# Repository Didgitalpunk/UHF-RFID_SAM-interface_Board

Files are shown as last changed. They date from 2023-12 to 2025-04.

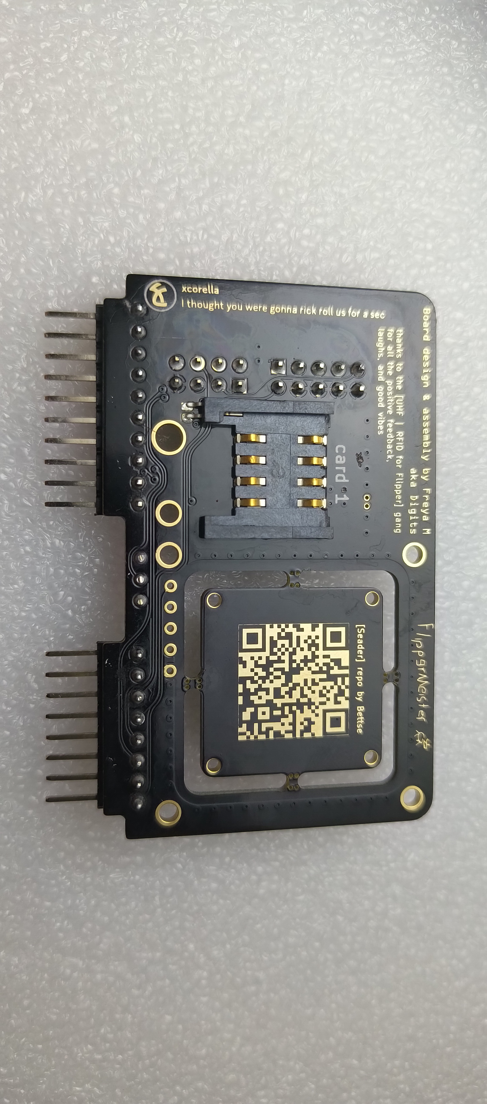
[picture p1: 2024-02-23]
P_20240223_211543.jpg

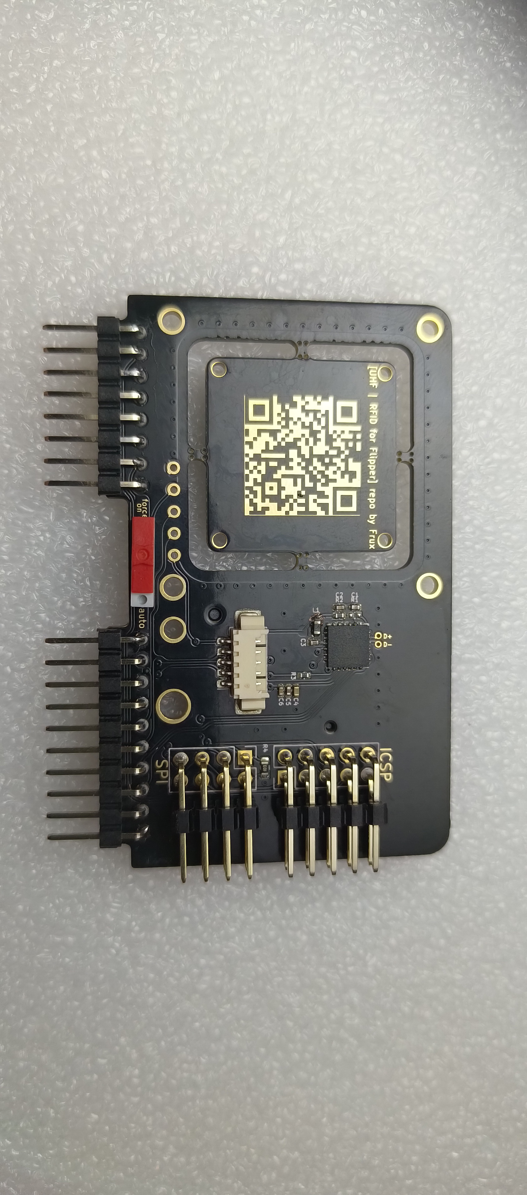
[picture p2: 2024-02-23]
P_20240223_211611.jpg

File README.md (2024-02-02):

# UHF-RFID SAM interface Board
A PCB for connecting UHF-RFID readers to your flipper, and a SEC1210 iC to allow you to interface and use a SAM.
Also has a 6 pin ICSP header and an SPI header to use with various FAPs.

This board is made for the flipper zero and uses https://github.com/frux-c/uhf_rfid for the UHF-RFID part, and https://github.com/bettse/seader for the SAM part.
The SPI and ICSP headers on this board are here for use with the SPI_Mem_Manager fap, and the AVR_Flasher fap respectively, among, I'm sure, others faps.

Thanks to the UHF|RFID gang over on the flipper zero discord for all the nice comments, all the info, and especially, the initial push on the UHF|RFID project!

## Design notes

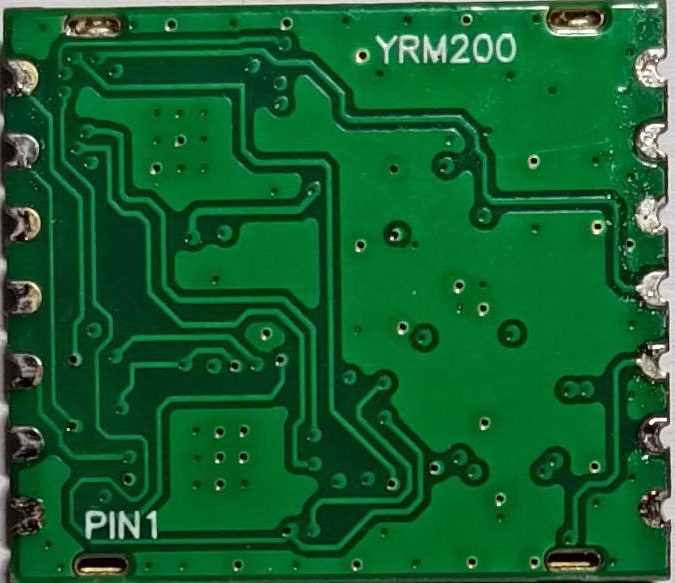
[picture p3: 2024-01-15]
YRM1001/YRM200/back.jpg

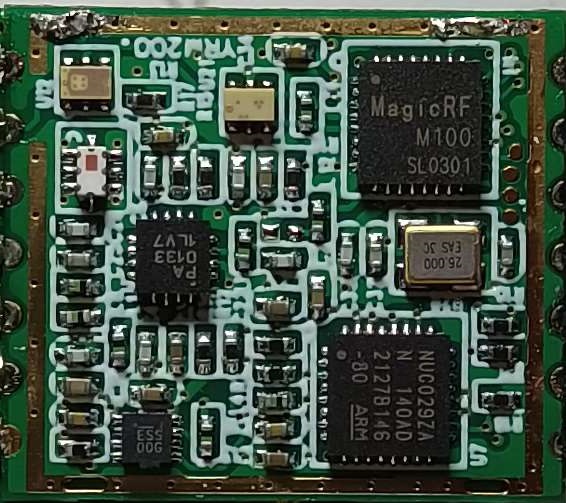
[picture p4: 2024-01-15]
YRM1001/YRM200/front.jpg

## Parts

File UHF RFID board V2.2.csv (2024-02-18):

Reference | Value | Footprint | Source | Qty
C1, C3, C5, C8 | 1uF | Capacitor_SMD:C_0402_1005Metric | https://www.mouser.fr/ProductDetail/Murata-Electronics/GRM155R61C105KA12J?qs=hNud%2FORuBR0BebdCvsO0Bw%3D%3D | 4
C2, C6, C9 | 0.1uF | Capacitor_SMD:C_0402_1005Metric | https://www.mouser.fr/ProductDetail/581-KGM05AR51A104KH | 3
C4, C7 | 10uF | Capacitor_SMD:C_0402_1005Metric | https://www.mouser.fr/ProductDetail/81-GRM155R61A106ME1J | 2
D1 | LED | Custom LEDs:side-edge mount | https://www.mouser.fr/ProductDetail/604-APA1606VRBXF5MAV | 1
eSAM1, eSAM2 | ~ | Custom footprints:DFN-8-splitEP_5x5mm_P1.27mm_EP2.5x4mm |  | 2
J1-1 | FZ_full_module-1 | Flipper modules:FZ full module | https://www.mouser.fr/ProductDetail/855-M20-9961045 | 1
J1-2 | FZ_full_module-2 |  | https://www.mouser.fr/ProductDetail/855-M20-9960845 | 1
J2 | picoblade | Connector_Molex:Molex_PicoBlade_53261-0571_1x05-1MP_P1.25mm_Horizontal | https://www.mouser.fr/ProductDetail/Molex/53261-0571?qs=Z4ettq%2Fvyk9tUNWvtq%2FUoA%3D%3D | 1
J3 | SPI | Connector_PinHeader_2.54mm:PinHeader_2x04_P2.54mm_Vertical | https://www.mouser.fr/ProductDetail/Harwin/M20-9950445?qs=WS5Jv%252B%252Bx1qUpJ0yV%252BQiEtg%3D%3D | 1
J4 | ICSP | Connector_PinHeader_2.54mm:PinHeader_2x03_P2.54mm_Vertical | https://www.mouser.fr/ProductDetail/Harwin/M20-9950345?qs=%252Bk6%2F5FB6qrkhHG1%252BkQ5u%252BQ%3D%3D | 1
L1 | 2A/0.05DCR | Inductor_SMD:L_0603_1608Metric | https://www.mouser.fr/ProductDetail/Murata-Electronics/BLM18EG221SN1D?qs=uSeJpk%2F8In2DDeSj2a4KGA%3D%3D | 1
R1 | 1M | Resistor_SMD:R_0402_1005Metric | DNP | 0
R2 | 100K | Resistor_SMD:R_0402_1005Metric | https://www.mouser.fr/ProductDetail/Bourns/CR0402-FX-1003GLF?qs=URDPQ%2Fj0cz1ZruPSJQ7fsA%3D%3D | 1
R3, R5 | 43R | Resistor_SMD:R_0402_1005Metric | https://www.mouser.fr/ProductDetail/?qs=ePR1ZvdkOKKmGsQnUArpPA%3D%3D | 2
R4 | 10k | Resistor_SMD:R_0603_1608Metric | https://www.mouser.fr/ProductDetail/652-CR0603-JW-103ELF | 1
R6 | 330R | Resistor_SMD:R_0402_1005Metric | https://www.mouser.fr/ProductDetail/Bourns/CR0402-FX-3300GLF?qs=SFHnMgm9IsyaL104gdTOhg%3D%3D | 1
SAM1, SAM2 | SIM_Card | Custom footprints:SIMMP-00801B000-G sim card connector w plated holes | https://fr.farnell.com/multicomp/simmp-00601b000-g/connecteur-mini-sim-6pin/dp/2211802?st=sim | 2
U1 | YRM1001 | RFID_NFC_footprints:UHF_RFID_35x35_YRM1001_module_through-board no_header with mounting holes 35-40 | https://fr.aliexpress.com/item/1005005296512846.html | 1
U2 | SEC1210 | Package_DFN_QFN:QFN-24-1EP_5x5mm_P0.65mm_EP3.2x3.2mm | https://www.mouser.fr/ProductDetail/Microchip-Technology/SEC1210-I-PV-UR2?qs=Gd3Cm49KlLPWS64hHCSBQA%3D%3D | 1

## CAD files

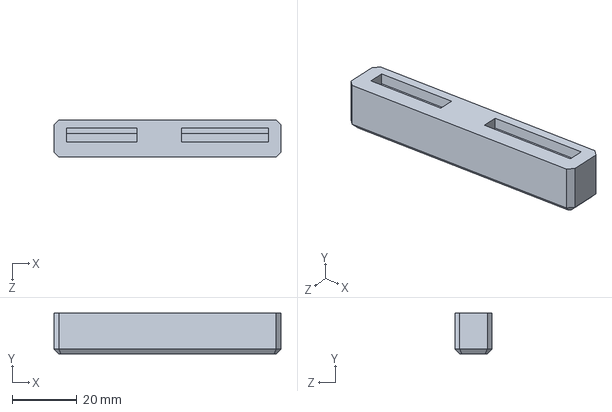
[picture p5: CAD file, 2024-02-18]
Case V2.0/case parts/UHF RFID board V2.0-Pin cover.SLDPRT
70.1 x 12.6 x 11.5 mm

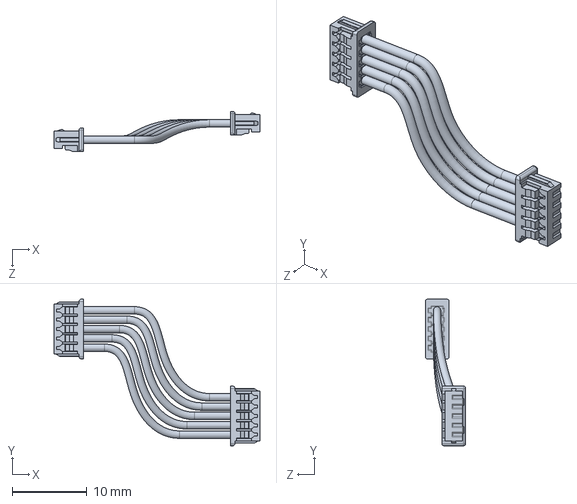
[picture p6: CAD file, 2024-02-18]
Case V2.0/picoblade cable.SLDPRT
27.6 x 19.6 x 5.40 mm

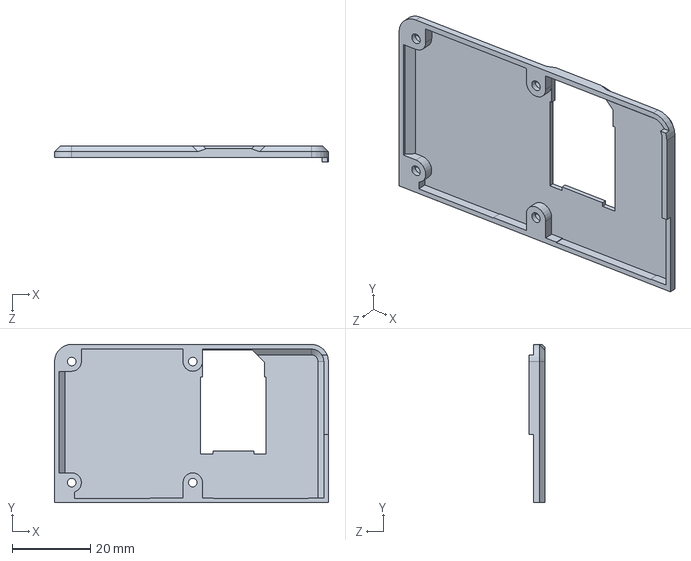
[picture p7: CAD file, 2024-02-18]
Case V2.0/case parts/UHF RFID board V2.0-Bottom case open SAM.SLDPRT
70.1 x 40.5 x 4.20 mm

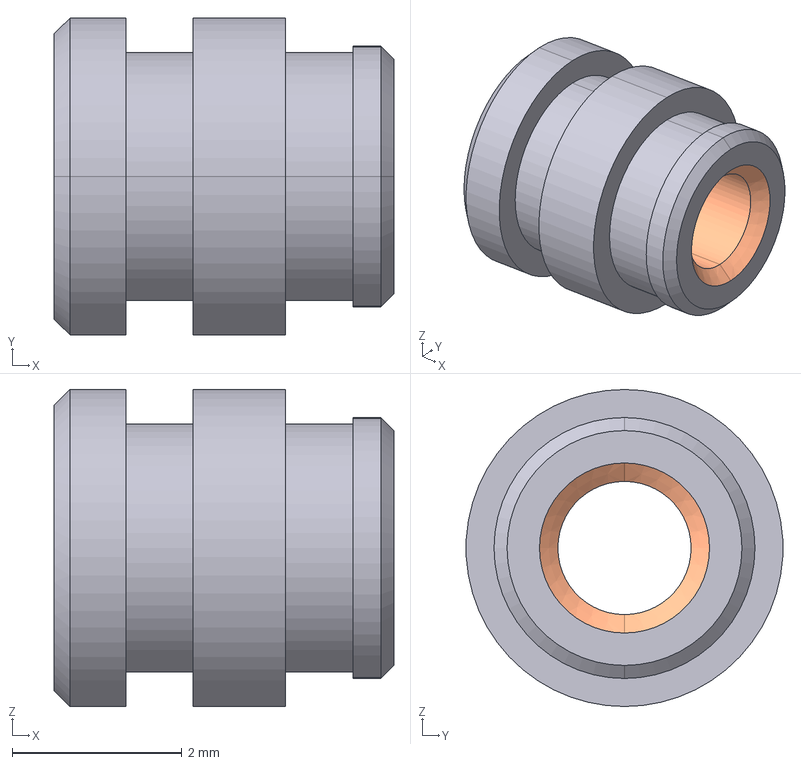
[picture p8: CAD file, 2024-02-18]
Case V2.0/IUTB-M2-PennEngineering-3D-02-02-2024.stp
4.00 x 3.72 x 3.73 mm

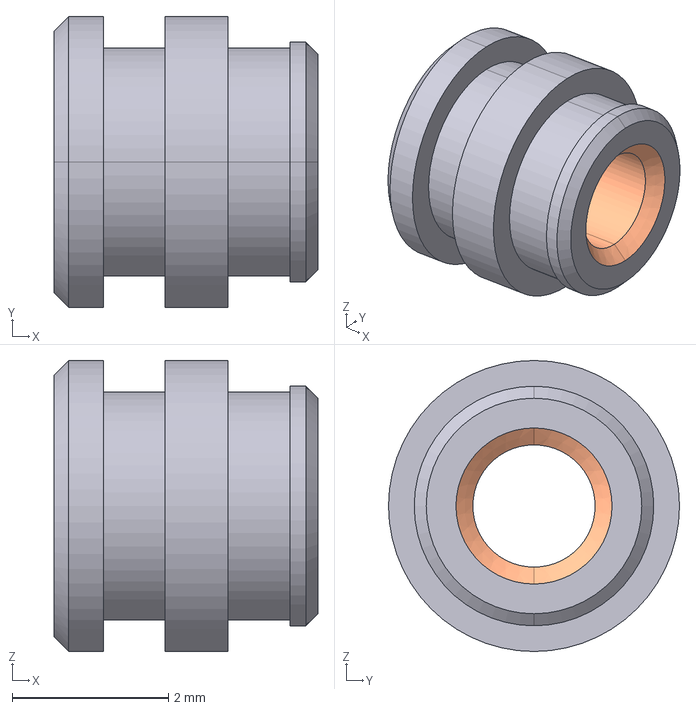
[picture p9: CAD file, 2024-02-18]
Case V2.0/IUTB-M2-318-PennEngineering-3D-02-02-2024.stp
3.38 x 3.73 x 3.73 mm

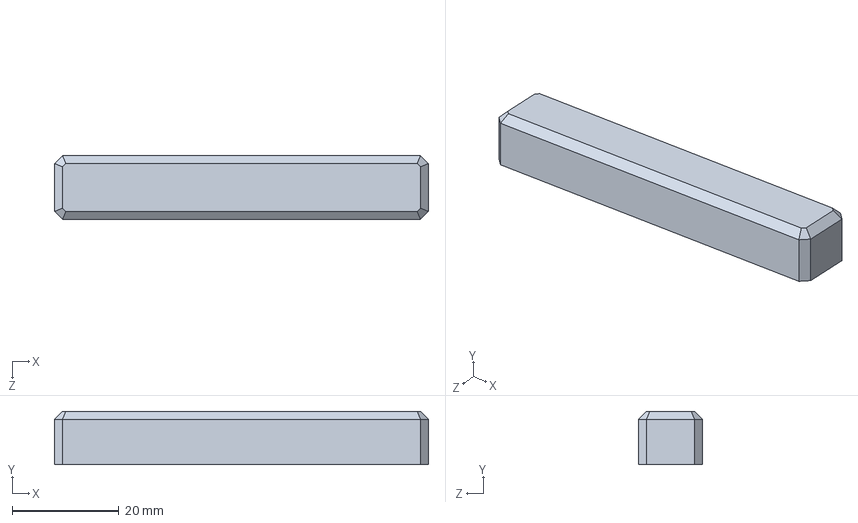
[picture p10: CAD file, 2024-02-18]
Case V2.0/case parts/open case cover.SLDPRT
70.1 x 10.0 x 12.0 mm

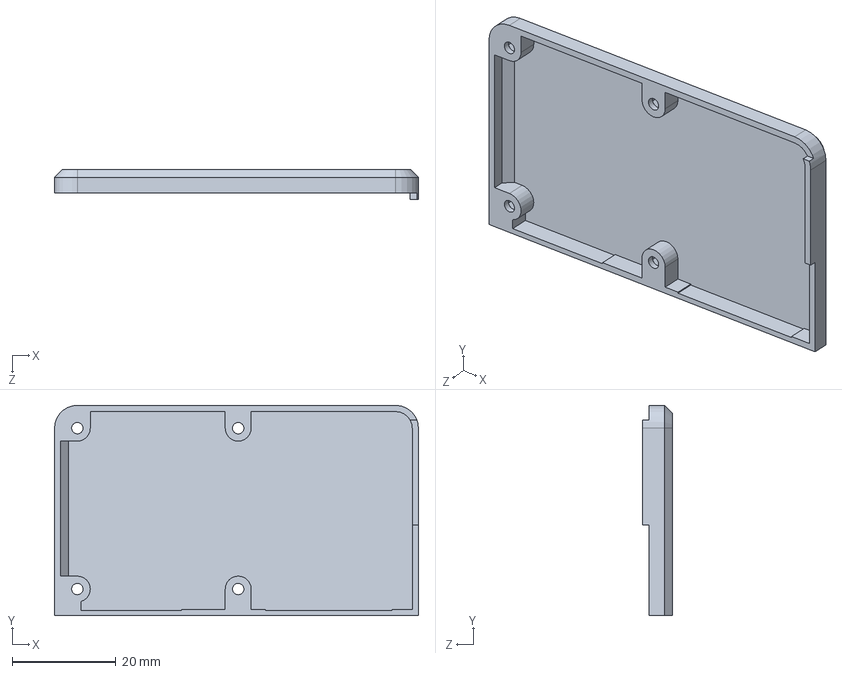
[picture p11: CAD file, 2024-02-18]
Case V2.0/case parts/UHF RFID board V2.0-Bottom case enclosed SAM.SLDPRT
70.1 x 40.5 x 5.70 mm

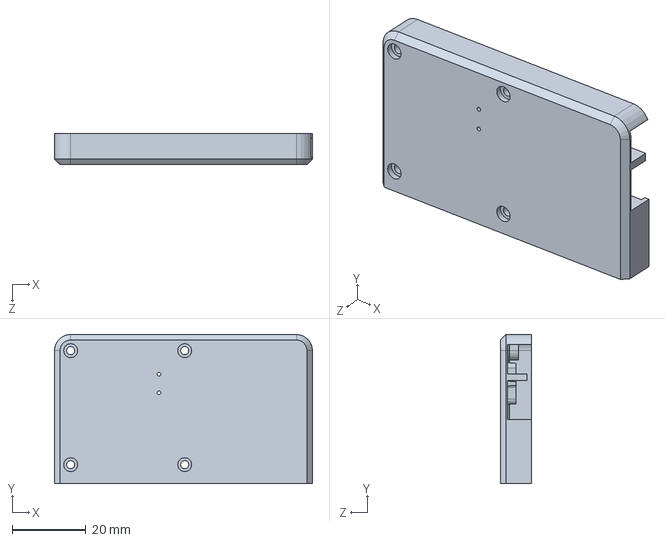
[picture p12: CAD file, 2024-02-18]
Case V2.0/case parts/UHF RFID board V2.0-Top case.SLDPRT
70.1 x 40.5 x 8.50 mm

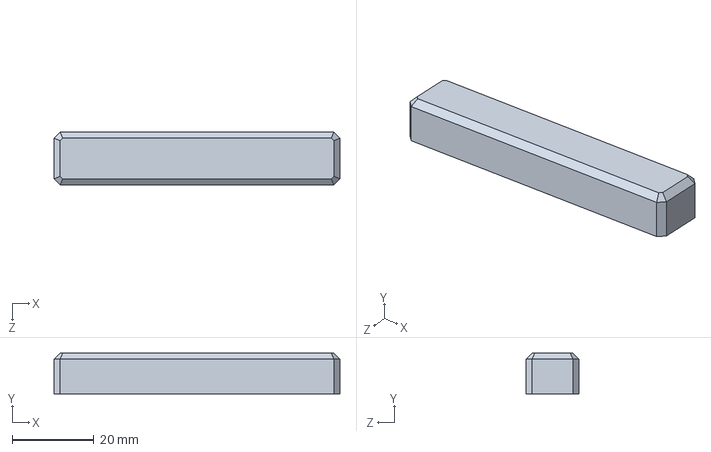
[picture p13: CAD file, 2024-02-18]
Case V2.0/case parts/closed case cover.SLDPRT
70.1 x 10.0 x 13.0 mm

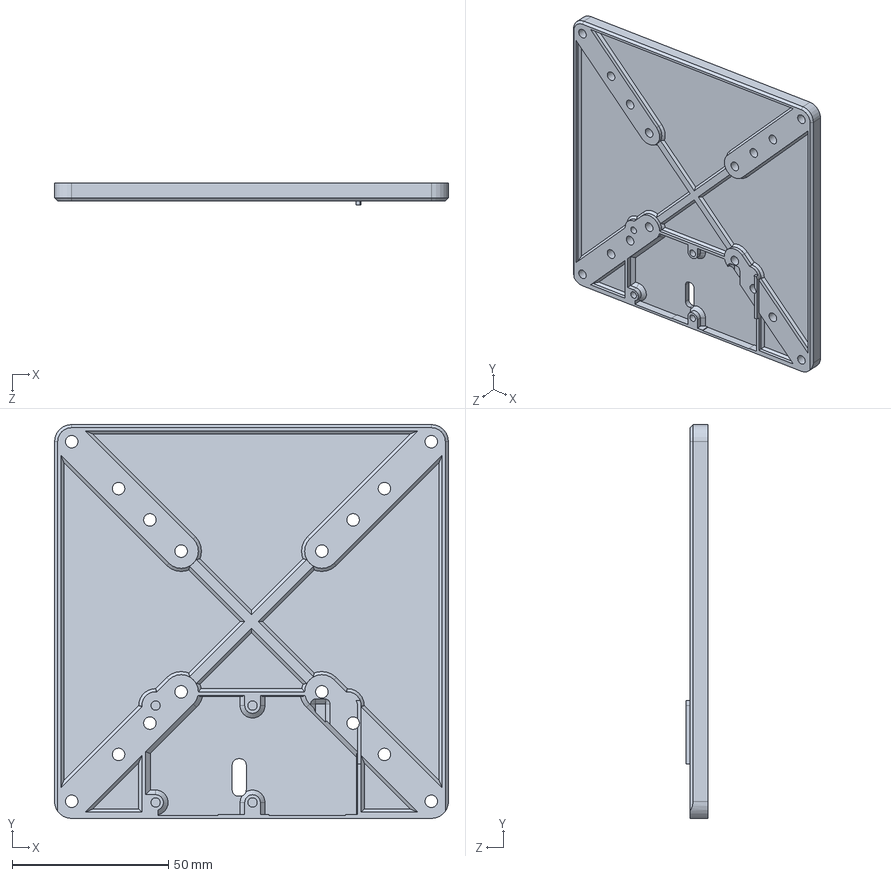
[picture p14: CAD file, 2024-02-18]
Case V2.0/case parts/UHF RFID board V2.0-bottom case closed big antenna.SLDPRT
126.0 x 126.0 x 6.95 mm

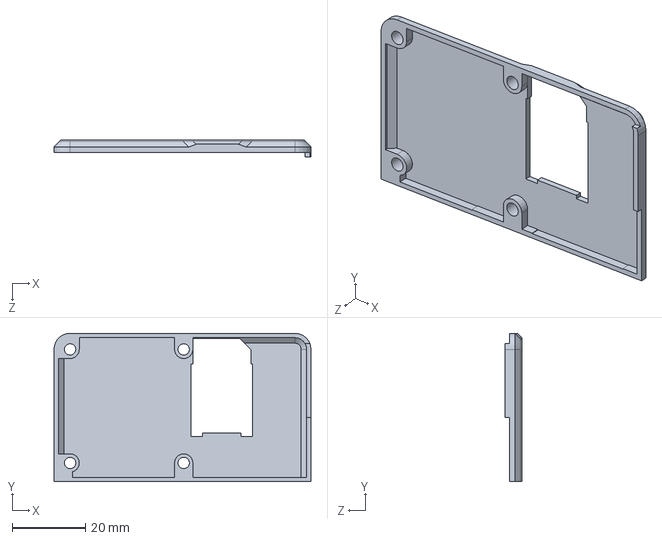
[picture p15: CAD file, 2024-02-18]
Case V2.0/case parts/UHF RFID board V2.0-Bottom case open SAM - inserts.SLDPRT
70.1 x 40.5 x 4.58 mm

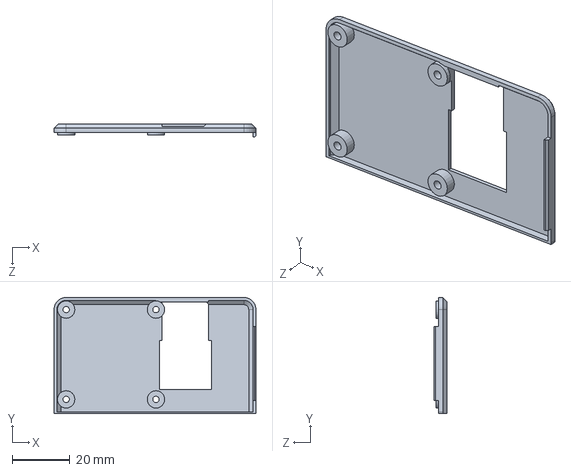
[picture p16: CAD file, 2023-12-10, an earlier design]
Case/case bottom.SLDPRT
69.7 x 40.1 x 4.60 mm

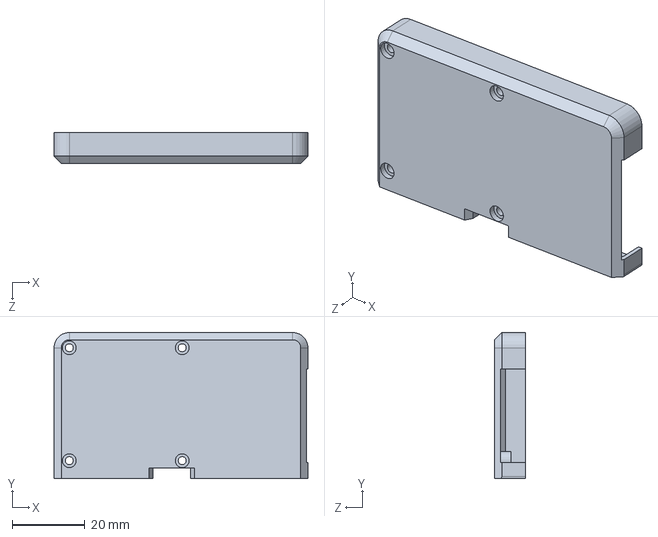
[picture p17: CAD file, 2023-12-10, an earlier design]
Case/case top.SLDPRT
69.7 x 40.1 x 8.51 mm

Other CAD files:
Case V2.0/case parts/UHF RFID board V2.0-Pin cover 1.6mm board.SLDPRT
Case V2.0/case parts/UHF RFID board V2.0-Bottom case enclosed SAM - inserts.SLDPRT
Case V2.0/case parts/UHF RFID board V2.0-Bottom case enclosed SAM - inserts.3MF
Case V2.0/case parts/UHF RFID board V2.0-Bottom case enclosed SAM.3MF
Case V2.0/case parts/UHF RFID board V2.0-Bottom case open SAM - inserts.3MF
Case V2.0/case parts/UHF RFID board V2.0-Bottom case open SAM.3MF
Case V2.0/case parts/UHF RFID board V2.0-Pin cover 1.6mm board.3MF
Case V2.0/case parts/UHF RFID board V2.0-Top case.3MF
Case V2.0/case parts/UHF RFID board V2.0-bottom case closed big antenna.3MF
Case V2.0/case parts/UHF RFID board V2.0-pin cover.3MF
Case/case bottom.3MF
Case/case top.3MF

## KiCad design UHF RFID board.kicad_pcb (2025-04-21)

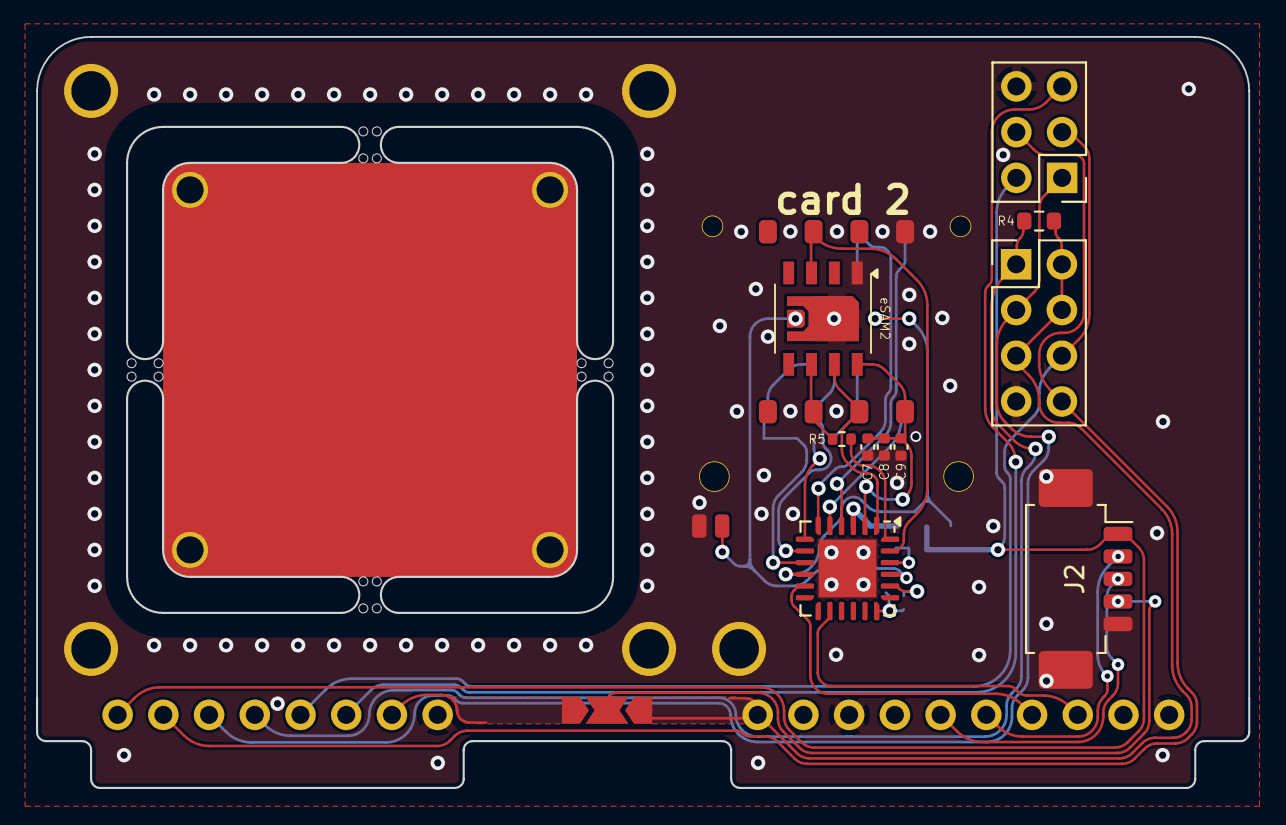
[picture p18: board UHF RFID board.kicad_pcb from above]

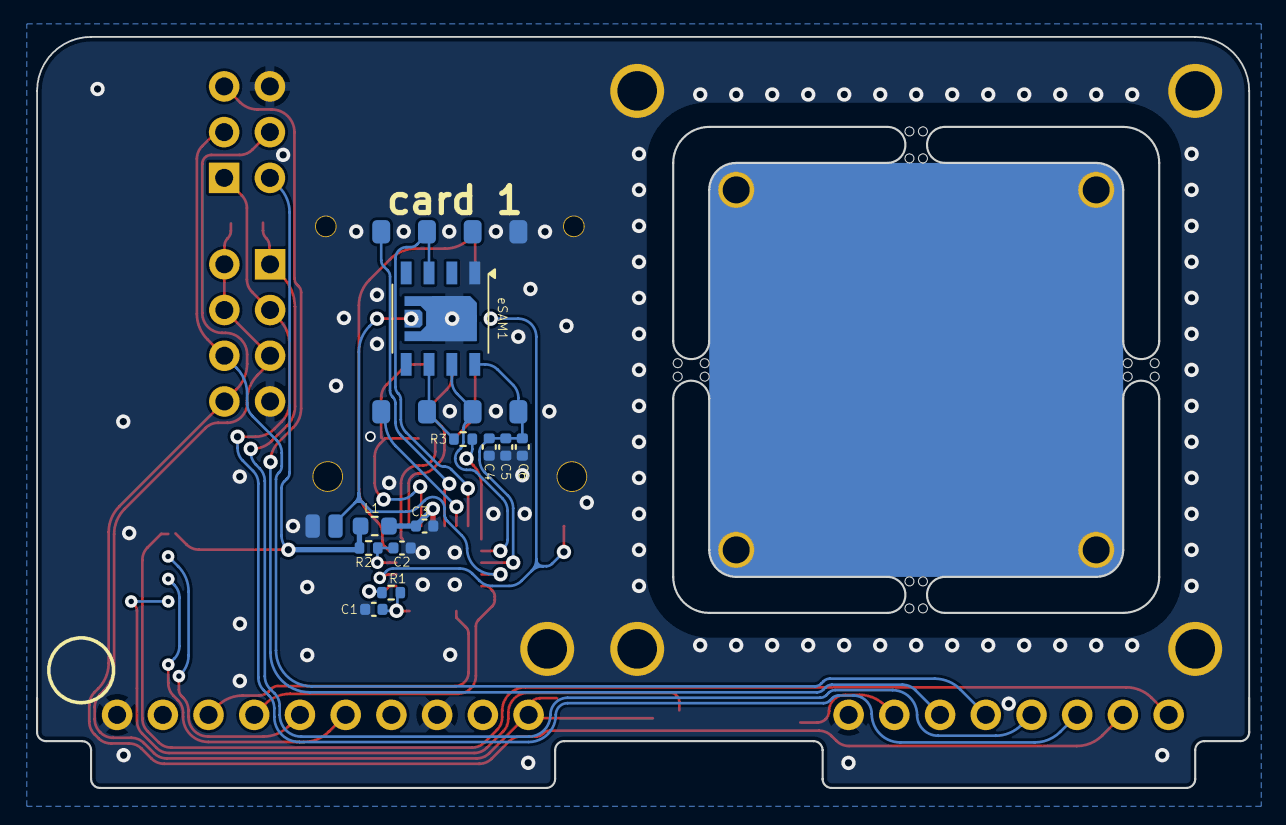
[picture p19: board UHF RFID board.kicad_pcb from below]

Board: 2 copper layers, 67.3 x 41.7 mm, 28 parts (13 on the bottom side), 32 nets.

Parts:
C1, C3, C5, C8: 1uF; C_0402_1005Metric
C2, C6, C9: 0.1uF; C_0402_1005Metric
C4, C7: 10uF; C_0402_1005Metric
J1: FZ_full_module; FZ full module
J2: picoblade; Molex_PicoBlade_53261-0571_1x05-1MP_P1.25mm_Horizontal
J3: SPI; PinHeader_2x04_P2.54mm_Vertical
J4: ICSP; PinHeader_2x03_P2.54mm_Vertical
JP1: SolderJumper_3_Open; SolderJumper-3_P2.0mm_Open_TrianglePad1.0x1.5mm
L1: 2A/0.05DCR; L_0603_1608Metric
R1: 1M; R_0402_1005Metric
R2: 100K; R_0402_1005Metric
R3, R5: 43R; R_0402_1005Metric
R4: 10k; R_0603_1608Metric
SAM1, SAM2: SIM_Card; SIMMP-00801B000-G sim card connector w plated holes
U1: YRM1001; UHF_RFID_35x35_YRM1001_module_through-board no_header with 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
U2: SEC1210; QFN-24-1EP_5x5mm_P0.65mm_EP3.2x3.2mm
[Seader] repo by Bettse: [Seader] repo by Bettse
[UHF | RFID for Flipper] repo by Frux: [UHF RFID for Flipper] repo by Frux
eSAM1, eSAM2: DFN-8-splitEP_5x5mm_P1.27mm_EP2.5x4mm

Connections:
+3.3V: J1.9 (3V3), J3.2, J3.4, J3.5, JP1.3 (B), R4.1
+3.3VA: C1.1, R1.2, U2.18 (VDD33)
+5V: J1.1 (5V), J2.1, J4.2, L1.1, R2.1
/EN: J2.4, JP1.2 (C)
/LED_ACT: R1.1, U2.20 (SC_LED_ACT_N/JTAG_TDO)
/PC0: J1.16 (C0), U2.14 (SPI1_MOSI/TXD)
/PC1: J1.15 (C1), U2.11 (SPI1_MISO/RXD)
/PC3: J1.7 (C3), JP1.1 (A)
/SC1_C4: SAM1.4 (C4), U2.5 (SC1_C4)
/SC1_C8: SAM1.8 (C8), U2.4 (SC1_C8)
/SC1_CLK: R3.2, SAM1.3 (CLK), eSAM1.6 (CLK)
/SC1_IO: SAM1.7 (I/O), U2.6 (SC1_IO), eSAM1.3 (SC_IO)
/SC1_PRSNT: SAM1.CSW (detect), U2.10 (SC1_PRSNT_N/JTAG_TMS), eSAM1.9 (PRSNT)
/SC1_RST: SAM1.2 (RST), U2.8 (SC1_RST_N), eSAM1.7 (RST)
/SC1_VCC: C4.1, C5.1, C6.1, SAM1.1 (VCC), U2.9 (SC1_VCC), eSAM1.8 (VCC)
/SC2_CLK: R5.2, SAM2.3 (CLK), eSAM2.6 (CLK)
/SC2_IO: SAM2.7 (I/O), U2.23 (SC2_IO), eSAM2.3 (SC_IO)
/SC2_PRsNT: SAM2.CSW (detect), U2.21 (SC2_PRSNT_N/JTAG_TDI), eSAM2.9 (PRSNT)
/SC2_RST: SAM2.2 (RST), U2.1 (SC2_RST_N), eSAM2.7 (RST)
/SC2_VCC: C7.2, C8.2, C9.2, SAM2.1 (VCC), U2.2 (SC2_VCC), eSAM2.8 (VCC)
/UART_RX: J1.14 (RX), J2.2
/UART_TX: J1.13 (TX), J2.3
/VDD5: C3.1, L1.2, U2.3 (VDD5)
/~RESET: C2.1, R2.2, U2.22 (~RESET)
CLK: J1.5 (B3), J3.6, J4.3
CS: J1.4 (A4), J3.1, R4.2
GND: C1.2, C2.2, C3.2, C4.2, C5.2, C6.2, C7.1, C8.1, C9.1, J1.8 (GND), J1.11 (GND), J1.18 (GND), J2.5, J2.MP, J3.7, J4.6, SAM1.5 (GND), SAM1.DSW (detect), SAM2.5 (GND), SAM2.DSW (detect), U1.5 (mounting), U2.25 (VSS(flag)), eSAM1.1 (GND), eSAM2.1 (GND)
MISO: J1.3 (A6), J3.3, J4.1
MOSI: J1.2 (A7), J3.8, J4.4
unnamed: R3.1, U2.7 (SC1_CLK)
unnamed: R5.1, U2.24 (SC2_CLK)
RST: J1.6 (B2), J4.5

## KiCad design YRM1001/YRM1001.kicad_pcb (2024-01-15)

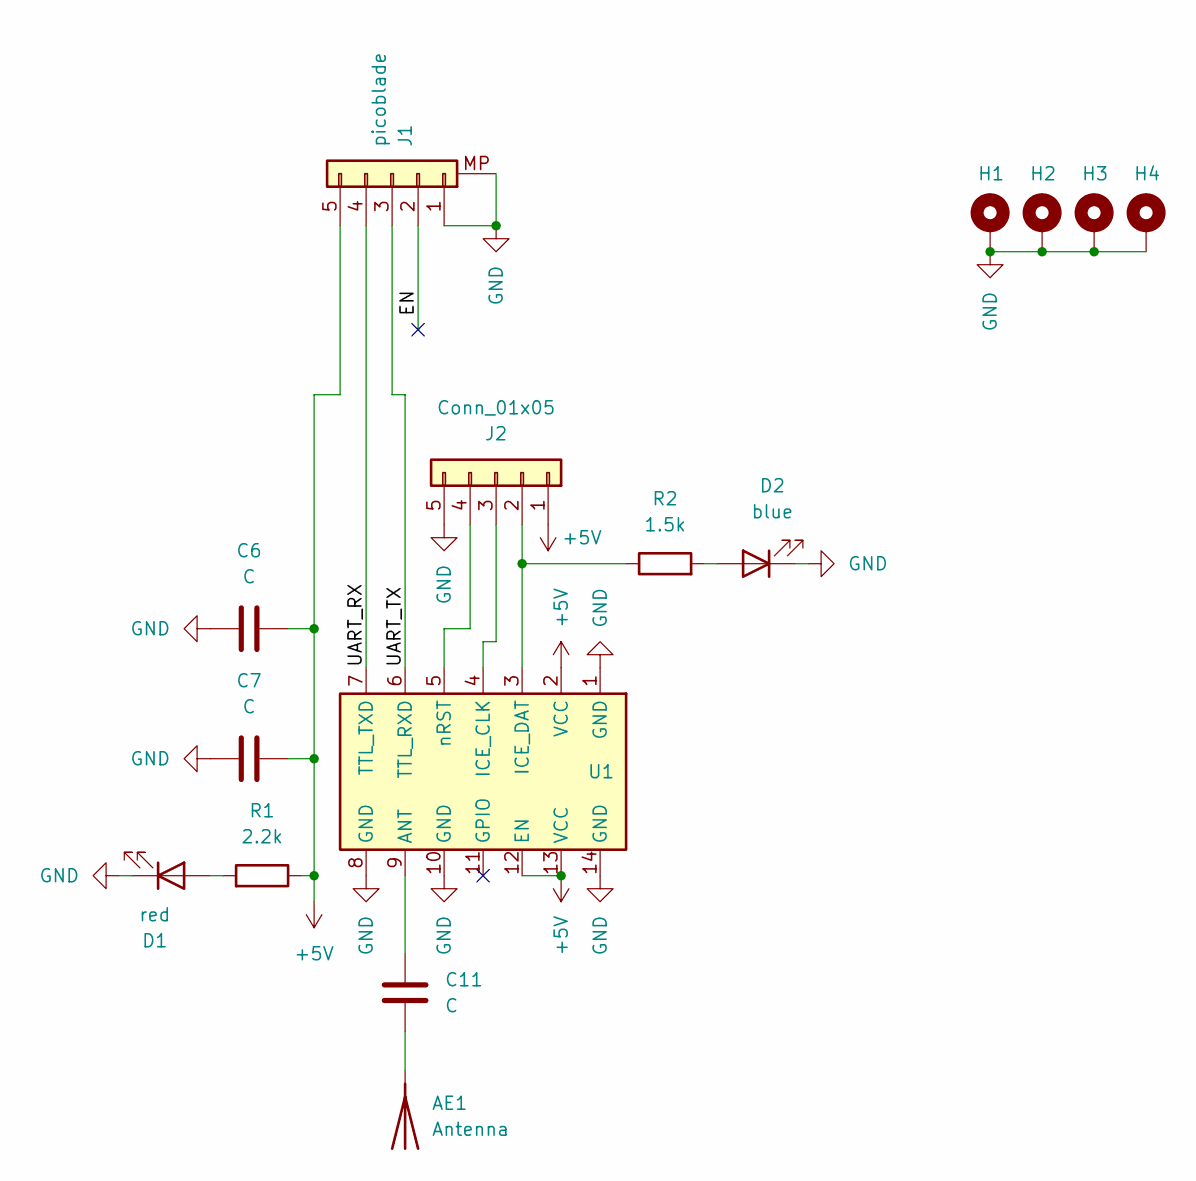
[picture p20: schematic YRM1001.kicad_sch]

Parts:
AE1: Antenna; UHF_RFID_25x25_antenna
C6, C7, C11: C; C_0805_2012Metric_Pad1.18x1.45mm_HandSolder
D1: red; LED_0805_2012Metric_Pad1.15x1.40mm_HandSolder
D2: blue; LED_0805_2012Metric_Pad1.15x1.40mm_HandSolder
H1, H2, H3, H4: MountingHole_Pad; MountingHole_2.2mm_M2_ISO7380_Pad
J1: picoblade; Molex_PicoBlade_53261-0571_1x05-1MP_P1.25mm_Horizontal
J2: Conn_01x05; PinHeader_1x05_P2.54mm_Vertical
R1: 2.2k; R_0805_2012Metric_Pad1.20x1.40mm_HandSolder
R2: 1.5k; R_0805_2012Metric_Pad1.20x1.40mm_HandSolder
U1: YRM200

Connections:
+5V: C6.1, C7.1, J1.5, J2.1, R1.1, U1.2 (VCC), U1.12 (EN), U1.13 (VCC)
/EN: J1.2
/UART_RX: J1.4, U1.7 (TTL_TXD)
/UART_TX: J1.3, U1.6 (TTL_RXD)
GND: C6.2, C7.2, D1.1 (K), D2.1 (K), H1.1, H2.1, H3.1, H4.1, J1.1, J1.MP, J2.5, U1.1 (GND), U1.8 (GND), U1.10 (GND), U1.14 (GND)
unnamed: AE1.1 (A), C11.1
unnamed: D1.2 (A), R1.2
unnamed: D2.2 (A), R2.2
unnamed: J2.2, R2.1, U1.3 (ICE_DAT)
unnamed: J2.3, U1.4 (ICE_CLK)
unnamed: J2.4, U1.5 (nRST)
unnamed: C11.2, U1.9 (ANT)

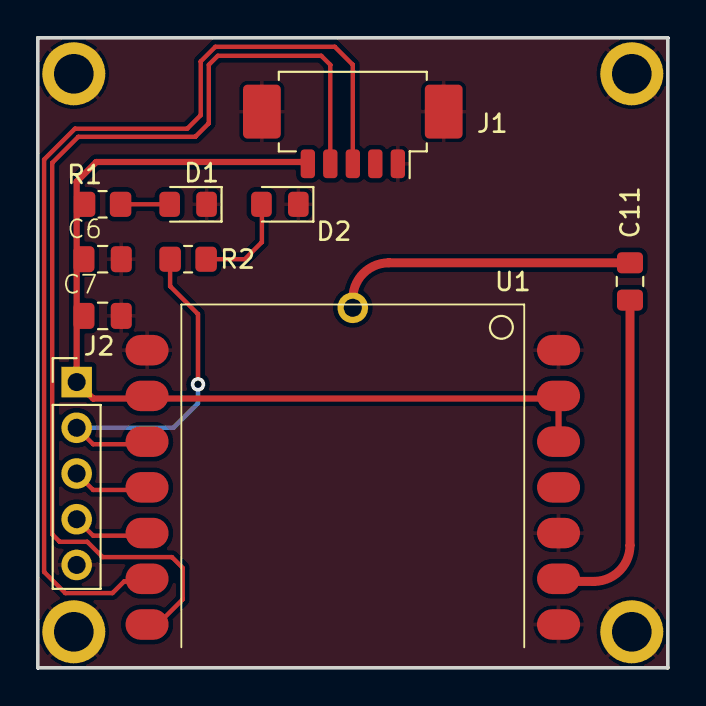
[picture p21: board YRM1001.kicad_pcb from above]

Board: 2 copper layers, 35.0 x 35.0 mm, 15 parts (1 on the bottom side), 11 nets.

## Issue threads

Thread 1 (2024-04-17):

PCB Fabrication: Suggested settings / pitfalls to avoid?

zacharyweiss, 2024-04-17:
Thanks for your work on this! I haven't seen these for sale anywhere so was planning on sending off to JLCPCB/PCBWay to have one fabbed. However, I'm inexperienced with EE / board design / PCB(A) fabrication, so wanted a sanity check from y'all; any specific settings that you would suggest using while exporting to gerber & requesting fabrication? Things I need to avoid / be aware of in the process?

Didgitalpunk, 2024-04-17:
Heya! you haven't seen these for sale because it's my own design, so noone's making them except me! and also they sold out in a day after I put up the listing ^^ ! I have V2 boards already made, but there's a looooong lead time on the sim slots I use, and no other alternative for them has been found yet, so it'll be a while before they get put up for sale on my tindie...
make sure to join the flipper discord and check out the [UHF | RFID for flipper] project thread to stay up to date :P

If you're inexperienced with pretty much anything PCB related, I'd suggest getting into it first and making a few boards before trying to fab someone else's design, it'll teach you what to look for and how to check their work! god knows V1 had mistakes 🤦‍♀️

Also this board uses components you cannot solder without hot air/reflow, so if you don't know how to do that, you're looking at getting them assembled by the board-house, and probably having them source components as well.

Didgitalpunk, 2024-04-17:
not an issue, just conversation. discord is the place to go for that.

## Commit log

2023-12-10 added board files. V1.1
    Added kicad files for V1.1
    Changes from (unrealeased) V1.0 > V1.1:
    - spread out D+ and D- labels to ensure no shorts are made if you try and solder to the D+ and D- lines
    - re-poured ground plane so L1 no longer shorts 5V to ground on both sides because of a non-updated ground pour
    - added name and version on top of board
    - re-routed pin header for YRM1001 since the connector was pinned differently than anticipated. none of the pins are duplicates of the picoblade connector save for ground and +5V
    - re-routed a few other traces and signals due to the YRM1001 pin header routing change.
    - thickened the border around both QR codes to ensure better detection with s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
    [UHF RFID board.kicad_pcb, UHF RFID board.kicad_sch]
2023-12-10 Update README.md
    added ICSP and SPI header info
2023-12-10 added case 3D model
    added case 3D model V1.0
    [case bottom.3MF, case bottom.SLDPRT, case top.3MF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]
2023-12-10 Added YRM1001 board files
    YRM1001 board reverse-engineering
    [YRM1001.kicad_pcb, YRM1001.kicad_sch]
2023-12-10 changed the footprint for SIM card to the correct one
    [UHF RFID board.kicad_pcb, UHF RFID board.kicad_sch]
2023-12-12 removed mentions of nard board on suggestion of the UHF|RFID gang
2024-01-15 Add files via upload
    updated board version to 1.2:
    - changed ICSP from 10 pin header to 6 pin header. 10 pin ICSP connections can be done with a 6 to 10 pin adapter cable.
    - changed name on board to UHF | RFID | SAM, removing '1/2 nard' from the name for clarity on what the board is and does.
    - removed header that was meant to hard-connect the UHF module to the board: it is not used for communication with the board after all.
    - updated the QR codes designs for better machine readability
    - various routing improvements.
    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
    [UHF RFID board.kicad_pcb, UHF RFID board.kicad_sch, YRM1001.kicad_pcb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]
2024-01-16 Version 2.0 RELEASE
    - removed M3 support hole for 50x50 modules: there was only one M3 hole anyway, so no good mechanical support. case for the board can designed with mounting holes for that size module if need be.
    - added second SAM slot as per SEC1210 datasheet.
    - rerouted the vast majority of the board to accommodate all the changes.
    - changed board thickness to 1.2 from 1.6 as per Flipper Zero module specs
    - repositioned the SAM slots close to the board edge for ease of access to the SAMs with a case on.
    - repositioned all of the components needed for the SEC1210 for addition of second SAM slot
    - repositioned Picoblade connector for addition of second SAM slot
    - repositioned ICSP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
    [UHF RFID board.kicad_pcb, UHF RFID board.kicad_sch]
2024-01-16 Updated README.md
    changed 10 pin ICSP to 6 pin ICSP
2024-01-17 finalization for V2.0 board production aspect
    - specified adhesive layers for all the back-mounted components
    - added footprint and model for kapton tape over USB breakout vias
    [UHF RFID board.kicad_pcb]
2024-02-02 Update V2.1
    - modified schematic to add iClass SE processor chip connections and symbol
    - added footprints to enable direct mounting of iClass SE processor chips instead of using a SAM (https://www.hidglobal.com/products/sio-processor)
    - added e.e.
    - routing
    [UHF RFID board.kicad_pcb, UHF RFID board.kicad_sch]
2024-02-18 fixes + bom, end of work on V2
    Fixed some footprint directory inconsistencies and errors dating form at least the start of the SAM integration phase for some, Cleaned up / reworked some footprints and finalized others.
    Fixed some BOM links being incorrect and/or missing.
    That concludes work on V2. Next additions will go towards V3 if there ever is one, but the board is now getting very cramped, and will be in a branch now that I know how those work.
    [UHF RFID board V2.2.csv, UHF RFID board.kicad_pcb, UHF RFID board.kicad_sch]
2024-02-18 added case files for V2 board
    added closed and open bottoms, insert and nuts versions, top, large antenna version, pin cover and main design files
    [IUTB-M2-318-PennEngineering-3D-02-02-2024.stp, IUTB-M2-PennEngineering-3D-02-02-2024.stp, UHF RFID board V2.0-Bottom case enclosed SAM - inserts.3MF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]
2024-02-23 added V1 board pictures
    Added front and back pictures for V1 board
2024-03-03 V2.3 release
    Switched a resistor and capacitor to B.cu to ensure they don't get ripped off when removing the picoblade connector. depending on further testing to see if I can get the LEDout working on the SEC chi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
    Cleaned up routing a bit due to that change.
    [UHF RFID board.kicad_pcb, UHF RFID board.kicad_sch]
2024-03-03 fixed some rounded tracks that were no longer arcs
    [UHF RFID board.kicad_pcb]
2024-03-04 removed no longer needed features (LEDs, USB)
    After testing it turns out the USB port on the SEC1210 UART version does not seem to be enabled. Therefore there's no way to program the chip to enable the LED output.
    Removed unneeded D1, D2, R6, and re-positioned R1 and C1 thanks to the extra space.
    updated schematic with DNP tags for D1, D2, R6.
    [UHF RFID board.kicad_pcb, UHF RFID board.kicad_sch]
2024-03-12 futureproofing for automated production
    Added fiducial markers for automated PNP machine assembly capability.
    updated version from 2.4 to 2.5
    added version info in schematic, along with title and my name for credit
    [UHF RFID board.kicad_pcb, UHF RFID board.kicad_sch]
2024-04-29 ease of assembly update
    added pin 1 marker on silkscreen for eSAM footprints, previously pin 1 was denoted by a chamfer in the center pad
    [UHF RFID board.kicad_pcb]
2024-05-09 V2.5.2 production update
    - removed unused + out-of-bounds mounting holes for the yrm1003 module that could throw errors in fab houses
    - corrected SIMMP-00801B000-G sim slot footprint, fab outline was bigger than the part, and model was not accurate for the part.
    [UHF RFID board.kicad_pcb]
2024-05-09 V2.5.3 yrm footprint center pad corner rounding
    [UHF RFID board.kicad_pcb]
2024-05-15 Version 2.5.4 - copper to board edge fix
    copper to board edge clearance was erroneously set to 0 instead of .254mm . PCB still functioned fine, this is purely to aid manufacturing and prevent manufacturers from throwing errors at you.
    [UHF RFID board.kicad_pcb]
2025-04-21 V2.6.0
    - flipped the inputs of the picoblade connector, so there's no longer a need for a pass-through cable which in hindsight, good. it seemed dumb a long time ago, but you live and learn. Now the off-the shelf cable from Molex (P/N: 151340500) will work as-is, no rewiring needed.
    - nudged the whole SAM stuff 1mm higher, which should no longer hinder connecting/disconnecting the picoblade cable in some cases.
    (previously if a SIM slot was soldered in CARD 2, the connector would barely hit the end of the SIM slot. Now it doesn't.)
    - updated board version number to V2.6.0
    [UHF RFID board.kicad_pcb, UHF RFID board.kicad_sch]
2025-10-01 footprint, updated BOM. staying at release 2.6.0
    added secondary footprint for the SIM slot to use a sim slot that's still available (amphenol 7111S1615A01LF )
2025-10-01 Delete UHF RFID board V2.2.csv
    removed old BOM file
2026-01-28 Update README with usage and distribution guidelines
    Clarify usage terms for the board design and distribution.
    (this commit message was created by copilot, but it's a good description)
